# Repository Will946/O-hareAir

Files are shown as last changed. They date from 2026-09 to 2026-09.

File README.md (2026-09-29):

# O'Hare Air

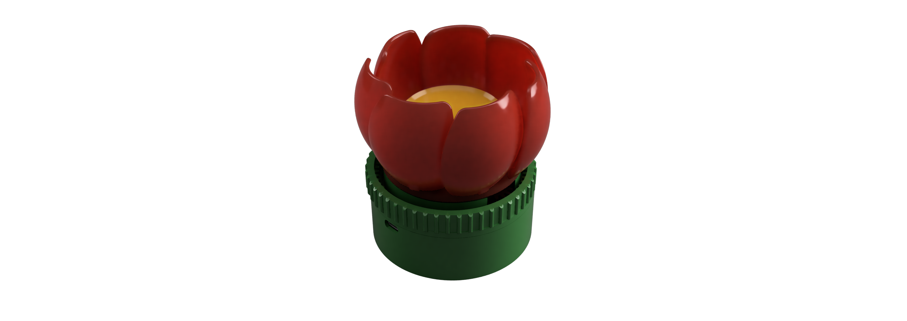
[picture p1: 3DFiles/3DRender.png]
O'Hare Air, assembled and running


A desktop air quality monitor shaped like a flower. It watches temperature, humidity, and air quality (eCO2/eTVOC/AQI-UBA) with a ScioSense ENS161 + ENS210, points a physical stepper-driven needle at the current rating, glows green-to-red through an RGB LED, and serves a full live dashboard over Wi-Fi with history and CSV export. No app, no cloud, no account.

---

## Where the name comes from

The name is taken from The Lorax (2012). In the film, Aloysius O'Hare is the mayor of Thneedville and the founder/CEO of "O'Hare Air," a company that sells bottled air to the town after industrial pollution ruined the natural air supply. This project borrows the name "O'Hare Air" for a device that measures real air quality.

---

## Table of contents

- [Features](#features)
- [How it all fits together](#how-it-all-fits-together)
- [Hardware — two PCB generations](#hardware--two-pcb-generations)
  - [V1 — ESP32-S3 dev-board shield](#v1--esp32-s3-dev-board-shield)
  - [V2 — custom ESP32-H2 module board](#v2--custom-esp32-h2-module-board)
  - [V1 vs V2 at a glance](#v1-vs-v2-at-a-glance)
- [Firmware](#firmware)
  - [Startup and timing](#startup-and-timing)
  - [How air quality is measured and calculated](#how-air-quality-is-measured-and-calculated)
  - [Temperature and humidity](#temperature-and-humidity)
  - [The needle](#the-needle)
  - [The LED](#the-led)
  - [History logging](#history-logging)
- [The web dashboard](#the-web-dashboard)
- [Flashing it yourself](#flashing-it-yourself)
- [Known limitations](#known-limitations)

---

## Features

- **Real air-quality sensing**: ScioSense ENS161 (eTVOC, eCO2, and an onboard 1-5 AQI-UBA rating) plus an ENS210 for temperature and humidity.
- **A physical gauge**: a 28BYJ-48 stepper motor sweeps a needle from 0° to 180° across five ratings: Excellent, Good, Moderate, Poor, Unhealthy.
- **A living LED**: a smooth green-to-red gradient that tracks the current rating, and a slow blue pulse while the sensor is still warming up.
- **A full web dashboard**: live readings, up to seven days of on-device history with min/avg/max, CSV export, and manual needle/LED control, all served directly from the board over Wi-Fi.
- **Two hardware generations**: a shield that plugs onto an off-the-shelf ESP32-S3 dev board (V1), and a from-scratch, coin-sized board built around a bare ESP32-H2 module (V2).
- **A 3D-printed flower enclosure**, because an air monitor sitting on your desk should look like it belongs there.

---

## How it all fits together

```
        ENS210 (temp/RH) ──┐
                            ├──► ESP32 ──► 28BYJ-48 stepper ──► needle (0°-180°)
        ENS161 (AQI-UBA,   ─┘      │
        eTVOC, eCO2)               ├──► RGB LED (green → yellow → orange → red)
                                    │
                                    └──► Wi-Fi ──► built-in web dashboard
                                              (Live / History / Needle tabs)
```

Both sensors sit on the same I2C bus. Every reading cycle, the firmware pulls temperature and humidity from the ENS210, feeds them to the ENS161 as environmental compensation (metal-oxide gas sensors need to know how hot and humid the air is to interpret resistance changes correctly), then reads the ENS161's eTVOC, eCO2, and AQI-UBA registers. AQI-UBA, the sensor's own 1-5 classification, is what drives the needle and the LED. Everything is also pushed out over the board's Wi-Fi web server so it's watchable from a phone or laptop in real time.

---

## Hardware — two PCB generations

### V1 — ESP32-S3 dev-board shield

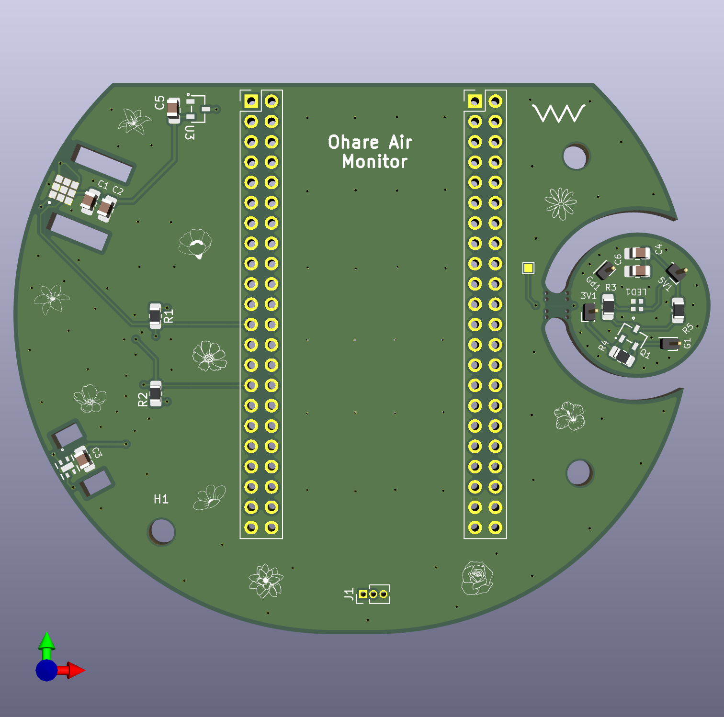
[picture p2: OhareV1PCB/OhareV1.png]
V1 PCB


V1 is a **shield**: a round board with two 2×22 headers (`J9`/`J10`) that plug directly onto an **ESP32-S3-DevKitC-1** dev board, using its pinout exactly. Rather than design a whole MCU circuit, V1 borrows the dev board's regulator, USB-to-serial bridge, and antenna, so the custom PCB only has to carry the sensors, the LED driver, and a 1.8 V rail.

**On the shield itself:**

| Ref | Part | Purpose |
|---|---|---|
| U1 | ENS161-BLGT | Air quality sensor (I2C `0x52`), eTVOC, eCO2, AQI-UBA |
| U2 | ENS210-LQFM | Temperature/humidity sensor (I2C `0x43`) |
| U3 | MCP1700T-1802E | Linear regulator, 3.3 V → 1.8 V for the ENS161's `VDD` rail |
| R1, R2 | 10 kΩ | I2C pull-ups (SCL/SDA) |
| C1–C6 | 0.1 µF / 10 µF | Decoupling for the sensors and the LED |
| Q1 | BSS138 | N-MOSFET level shifter, 3.3 V logic → 5 V for the LED data line |
| LED1 | IN-PI15TAT5R5G5B | A single addressable RGB LED |
| J1 | 3-pin socket | Breaks out 5 V / 3.3 V / LED data for the LED module |
| H1–H3, TP1 | — | Mounting holes and a test point |

The two headers expose every GPIO the dev board offers, but the sketch only actually uses a handful of them: `GPIO8`/`GPIO9` for I2C, `GPIO4`–`GPIO7` for the stepper's four ULN2003 driver inputs, and `GPIO48` for the dev board's own onboard RGB LED. 

Full schematic: [`OhareV1PCB/OhareV1Sch.pdf`](OhareV1PCB/OhareV1Sch.pdf). Manufacturing files (Gerbers) are in [`OhareV1PCB/Gerber.zip`](OhareV1PCB/Gerber.zip); KiCad source is [`OhareV1.kicad_pcb`](OhareV1PCB/OhareV1.kicad_pcb) / [`OhareV1.kicad_sch`](OhareV1PCB/OhareV1.kicad_sch).

### V2 — custom ESP32-H2 module board

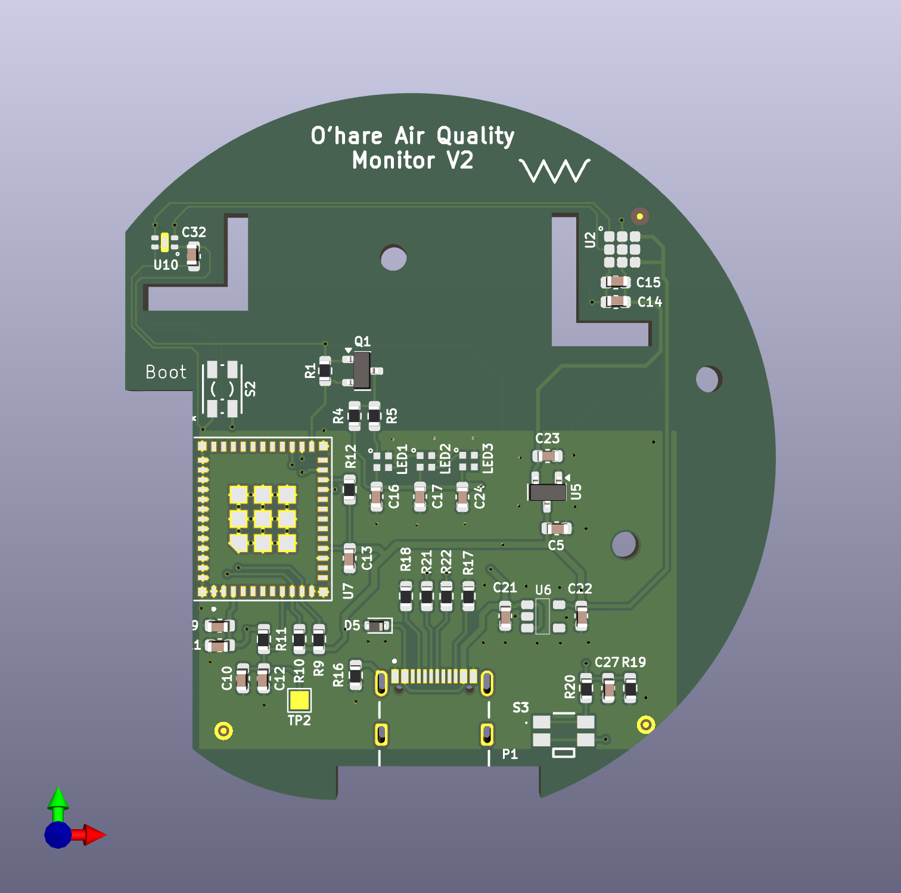
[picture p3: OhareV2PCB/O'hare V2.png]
V2 PCB


V2 throws out the dev board entirely. Instead of two headers plugging into someone else's board, V2 puts an **ESP32-H2-MINI-1** module (a tiny, low-power Espressif module, not a full development board) directly on the PCB, along with its own USB-C connector and its own power regulation. The result is dramatically smaller: the whole "computer" fits in the footprint of the module itself, not a full dev-board-shaped hole in the middle of the design.

**On the V2 board:**

| Ref | Part | Purpose |
|---|---|---|
| U7 | ESP32-H2-MINI-1 | The microcontroller: BLE + 802.15.4 (Zigbee/Thread) radio, **no Wi-Fi** (see below) |
| U2 | ENS161 | Air quality sensor (I2C `0x52`) |
| U10 | ENS210 | Temperature/humidity sensor (I2C `0x43`) |
| U6 | AP2205 | 3.3 V regulator (the board's main "3V3 bus") |
| U5 | AP2120 | 1.8 V regulator, for the ENS161's `VDD` |
| P1 | USB-C receptacle | Power and native USB flashing (the H2 has built-in USB, no separate USB-serial chip needed) |
| D5 | TPD1E10B06 | ESD/surge protection on the USB data lines |
| R21, R22 | 5.1 kΩ | USB-C CC pull-downs, so the board correctly identifies itself as a 5 V sink to chargers and power banks |
| Q1 | BSS138 | Same level-shifting job as V1: 3.3 V logic to 5 V LED data |
| LED1, LED2, LED3 | IN-PI15TAT5R5G5B | **Three** addressable RGB LEDs (labeled Front Left / Front Right / Rear Right on the silkscreen), daisy-chained, instead of V1's single LED |
| S2 | Push button | BOOT (bootloader entry for flashing) |
| S3 | Push button | Reset |

Full schematic: [`OhareV2PCB/OhareV2Sch.pdf`](OhareV2PCB/OhareV2Sch.pdf); KiCad source is [`OhareV2.kicad_pcb`](OhareV2PCB/OhareV2.kicad_pcb) / [`OhareV2.kicad_sch`](OhareV2PCB/OhareV2.kicad_sch).

### V1 vs V2 at a glance

| | V1 | V2 |
|---|---|---|
| MCU | ESP32-S3-DevKitC-1 (full dev board, plugged in via headers) | ESP32-H2-MINI-1 (bare module, soldered directly to the PCB) |
| Radio | Wi-Fi + BLE | BLE + 802.15.4 (Zigbee/Thread); no Wi-Fi |
| Size | Dev-board-sized | A fraction of that; the module is the board |
| Power in | Through the dev board's own USB-C | Native USB-C directly on the PCB |
| LEDs | 1 (drives the dev board's onboard LED) | 3, individually placed under the enclosure's petals |
| Flashing | Dev board's onboard USB-to-serial bridge | Native USB on the H2 itself |
| Firmware status | **Fully supported**, this is what the current sketch targets | **Current firmware is supported on new version |

---

## Firmware

The active firmware is [`Code/OhareAir/OhareAir.ino`](Code/OhareAir/OhareAir.ino), an Arduino sketch built for the **ESP32-S3 (V1)**. It's written directly against the ENS161 and ENS210 datasheets: talking to both sensors over I2C, driving the stepper needle and RGB LED, and serving the whole web dashboard, all from a single self-contained sketch.

### Startup and timing

On power-up, both sensors initialize immediately, but **nothing is read for the first 3 minutes.** The ENS161 needs that long to reach a stable operating temperature; reading it earlier just produces noise. During this warm-up the LED pulses a slow blue instead of showing a color it can't back up yet, and the needle stays parked at 0°.

Once warm-up ends, the firmware takes **one reading per minute**. A flower on a desk doesn't need second-by-second air-quality updates, and a slower cadence keeps the I2C bus quieter.

Each reading cycle:
1. Read temperature and humidity from the ENS210.
2. Write those values to the ENS161's compensation registers (`TEMP_IN` / `RH_IN`), so its gas readings account for the current conditions.
3. Give the ENS161 a moment to fold that compensation into its next internal measurement.
4. Read eTVOC, eCO2, and AQI-UBA off the ENS161.
5. Feed everything into the 5-minute history accumulator.
6. If Auto mode is on, hand AQI-UBA to the needle logic.

### How air quality is measured and calculated

The ENS161 is a metal-oxide gas sensor: it doesn't count individual VOC molecules, it measures how much a heated sensing element's electrical resistance shifts when exposed to reactive gases, then converts that into three numbers over I2C:

- **eTVOC** (equivalent Total Volatile Organic Compounds, in ppb): the chip's estimate of total VOC concentration, calibrated against ethanol as a reference gas. This is the sensor's actual measurement; everything else is derived from it.
- **eCO2** (equivalent CO2, in ppm): not a real CO2 measurement. It's estimated from the same VOC signal, so it tracks eTVOC almost exactly and should be read as "how stale does the air smell," not literal CO2 concentration.
- **AQI-UBA** (1-5): the chip's own onboard hygienic rating, computed internally by ScioSense's proprietary algorithm from its eTVOC signal, using threshold bands published by Germany's Federal Environmental Agency (Umweltbundesamt, hence "UBA"):

  | AQI-UBA | Rating | Approx. eTVOC |
  |---|---|---|
  | 1 | Excellent | 0 – 65 ppb |
  | 2 | Good | 65 – 220 ppb |
  | 3 | Moderate | 220 – 650 ppb |
  | 4 | Poor | 650 – 2,200 ppb |
  | 5 | Unhealthy | 2,200 ppb+ |

**AQI-UBA is what drives the needle and the LED**, rather than a hand-built formula. eTVOC and eCO2 are still read, displayed, and logged, but the rating itself comes straight from the ENS161's own proprietary onboard algorithm: ScioSense's classification, computed inside the chip from its own internal, self-compensating signal, not something calculated in software afterward. The trade-off is that AQI-UBA can't be corrected or offset after the fact the way a software-calculated number could; whatever the chip decides, the firmware trusts.

### Temperature and humidity

Raw ENS210 output is corrected by a fixed offset (`TEMP_OFFSET_C`, currently 5.56 °C) to account for the board's own self-heating from the MCU and Wi-Fi radio; an uncorrected reading on this hardware runs noticeably warmer than the actual room. This is a per-board constant; if you build your own, re-measure it against a reference thermometer and adjust.

### The needle

A 28BYJ-48 stepper motor (through a ULN2003 driver board) sweeps a needle across a 180° arc:

| Rating | Angle |
|---|---|
| Excellent | 0° |
| Good | 90° |
| Moderate | 115° |
| Poor | 140° |
| Unhealthy | 180° |

To avoid the needle twitching back and forth when AQI-UBA hovers right at a boundary, a new rating has to show up in **two readings in a row** (about two minutes) before the needle actually moves. Position is tracked in software as a step count from a zeroed home position. There's no physical limit switch, so the needle has to be manually set to 0° before every power-up; if the board resets while the needle is elsewhere, the software's idea of "0°" and the needle's real position will disagree until it's re-zeroed by hand.

### The LED

The LED (a single onboard RGB LED on V1; three chained LEDs, wired for that, on V2's hardware) fades smoothly between colors rather than snapping: green at AQI-UBA 1, sliding through yellow and orange, to red at AQI-UBA 5. During warm-up, before any reading exists, it pulses a slow blue instead. Brightness (0/10/30/60/100%) is adjustable from the dashboard and resets to 60% on every reboot; it isn't saved to flash.

### History logging

Every 5 minutes, the firmware saves one entry (the minimum, average, and maximum of temperature, humidity, AQI-UBA, eCO2, and eTVOC over that window) into a ring buffer sized for **7 days** (2,016 entries), packed into a fixed 32-byte record per entry. **This history lives entirely in RAM, not flash**; it's lost on every reboot or power cycle. A window where a sensor read failed is stored as an explicit "no data" marker rather than a guessed value, so a bad reading never silently drags down an average.

---

## The web dashboard

The board runs its own web server (`WebServer.h`) and serves a self-contained single-page dashboard: no external app, no cloud round-trip. Connect it to Wi-Fi, open its IP address in a browser, and you get three tabs:

**Live**

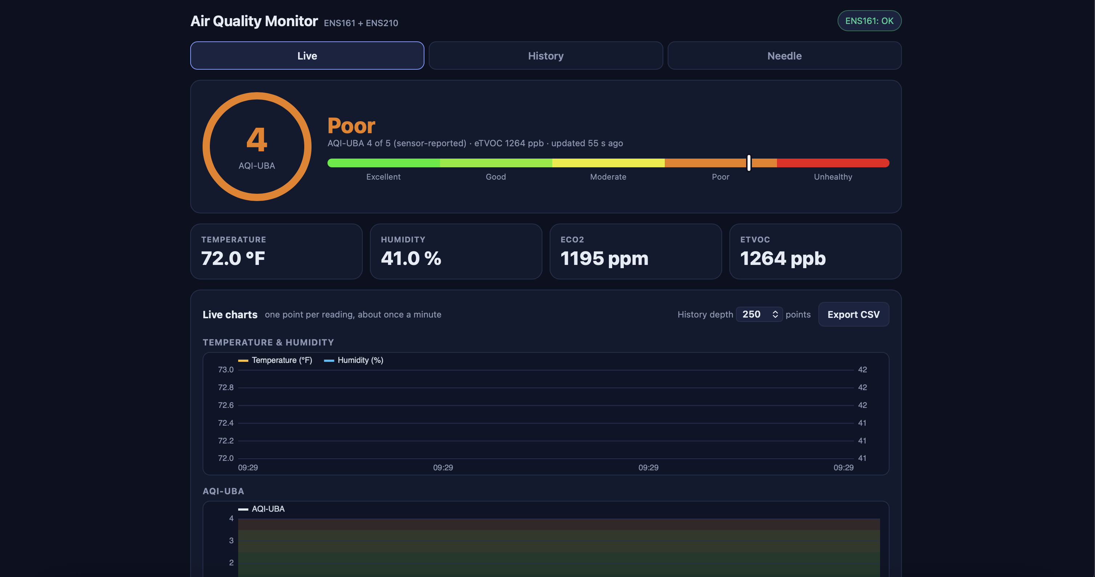
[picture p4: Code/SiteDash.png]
Live tab


The current AQI-UBA rating as a big color-coded number and name, a five-segment scale showing where it sits, temperature/humidity/eCO2/eTVOC cards, and three live-updating charts (temperature & humidity, AQI-UBA, and gas levels) that add one point per new reading, not per page refresh, so leaving the tab open doesn't flood the chart with duplicate points. LED brightness controls live here too.

**History**

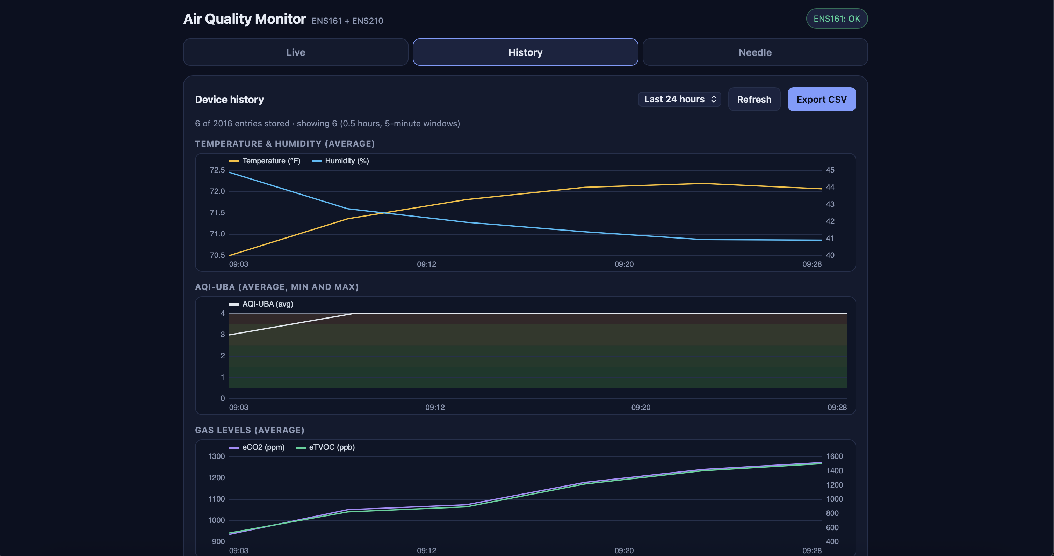
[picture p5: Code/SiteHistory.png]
History tab


The same charts, but built from the on-device 5-minute history instead of the live buffer, with a range selector (6 hours to 7 days) and CSV export.

**Needle**

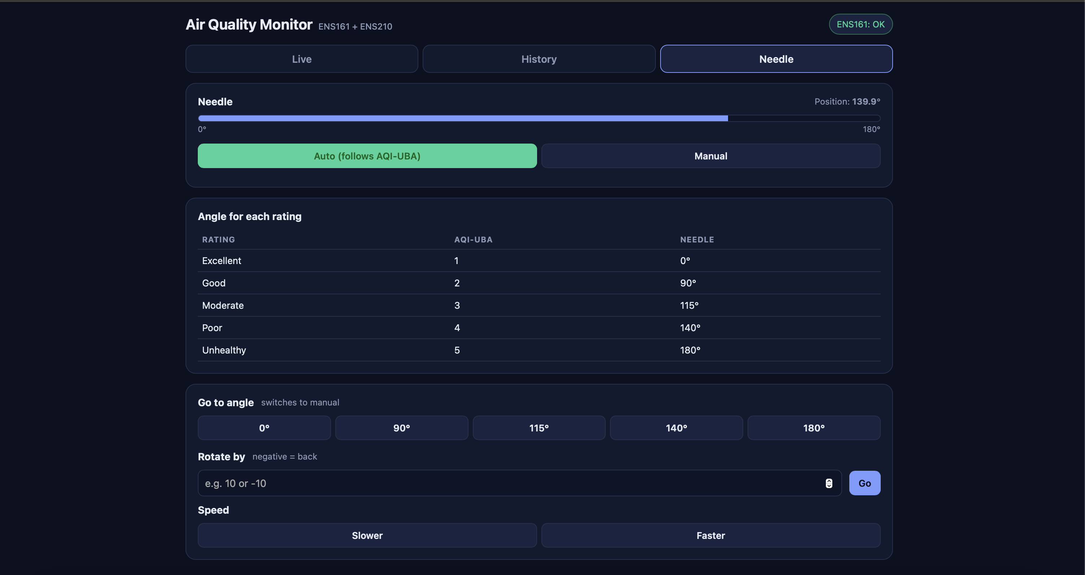
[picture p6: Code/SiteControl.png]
Needle tab


Manual control: an Auto/Manual toggle, a reference table of which AQI-UBA rating maps to which angle, one-tap "go to angle" buttons for each rating, a free-form rotate-by-degrees input, and motor speed adjustment.

**Endpoints**, for anyone scripting against it directly:

| Endpoint | Purpose |
|---|---|
| `GET /status` | Current reading, needle state, and device status as JSON |
| `GET /history?n=N` | The newest N history entries as compact JSON |
| `GET /rotate?degrees=X` | Rotate the needle by X° (switches to Manual) |
| `GET /goto?degrees=X` | Move the needle to an absolute angle (switches to Manual) |
| `GET /mode?auto=0\|1` | Switch between Auto and Manual |
| `GET /speed?direction=faster\|slower` | Adjust stepper speed |
| `GET /brightness?pct=X` | Set LED brightness, 0–100 |

---

## Flashing it yourself

1. Arduino IDE with the ESP32 board package installed, targeting an ESP32-S3 board (V1 hardware).
2. Install the **Adafruit NeoPixel** library. `Wire`, `WiFi`, and `WebServer` ship with the ESP32 core.
3. Open [`Code/OhareAir/OhareAir.ino`](Code/OhareAir/OhareAir.ino) and fill in your Wi-Fi credentials:
```cpp
   const char* ssid = "";
   const char* password = "";
```
4. Flash it, then open the Serial Monitor at 115200 baud; it prints the board's IP address once connected.
5. Set the needle to its physical 0° position before powering on, since the firmware has no way to detect where it actually is.
6. Open that IP address in a browser on the same network.

---

## Known limitations

- **Highly temperature- and humidity-dependent.** The ENS161 is a metal-oxide gas sensor: its readings shift with the temperature and humidity it's told to compensate for, and the board's own self-heating (from the MCU and Wi-Fi radio) pushes the ENS210's raw temperature well above the actual room temperature. That's corrected with a fixed offset (`TEMP_OFFSET_C`) tuned for this specific board; a different enclosure, a different MCU, or even just a different ambient environment can shift the true offset enough that eTVOC, eCO2, and AQI-UBA all read differently than they would with perfect compensation.
- **History doesn't survive a reboot.** It's RAM-only; a power cycle clears it.
- **The needle has no home sensor.** It has to be manually zeroed before every power-up.
- **Wi-Fi credentials are hardcoded** in the sketch, not configurable from the dashboard.
- **No OTA updates**: reflashing means plugging in over USB, which means having to disassemble the enclosure to access the port.

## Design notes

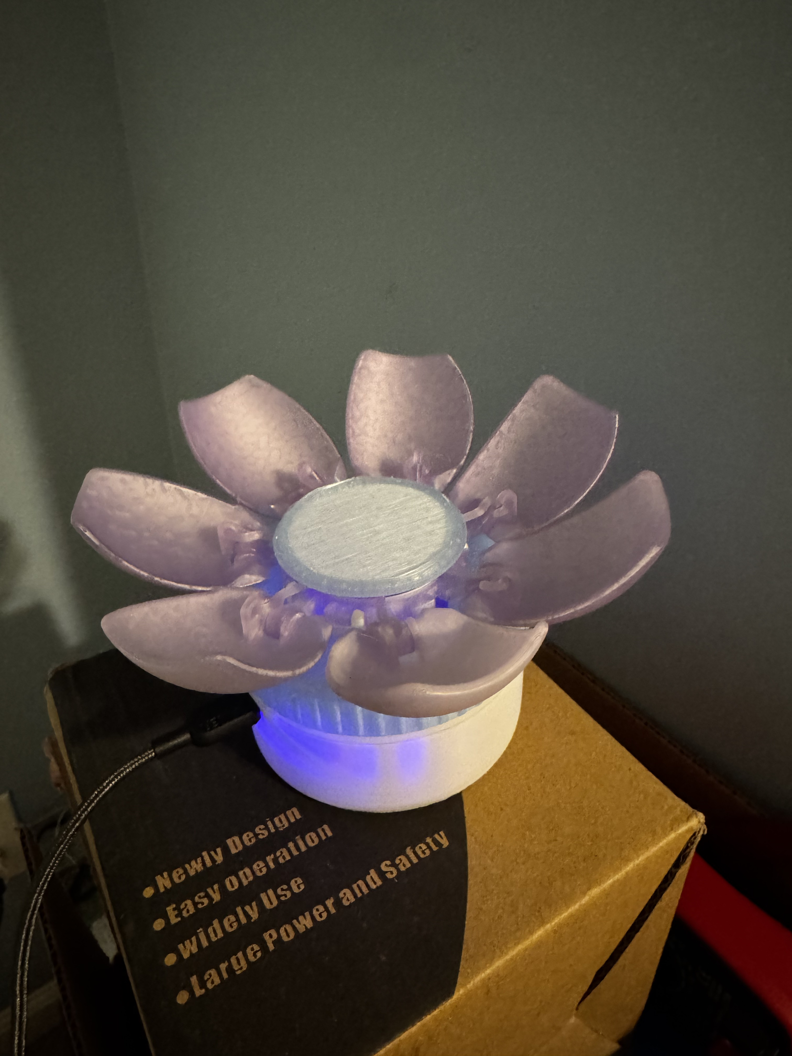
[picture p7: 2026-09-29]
3DFiles/OhareAir.jpeg

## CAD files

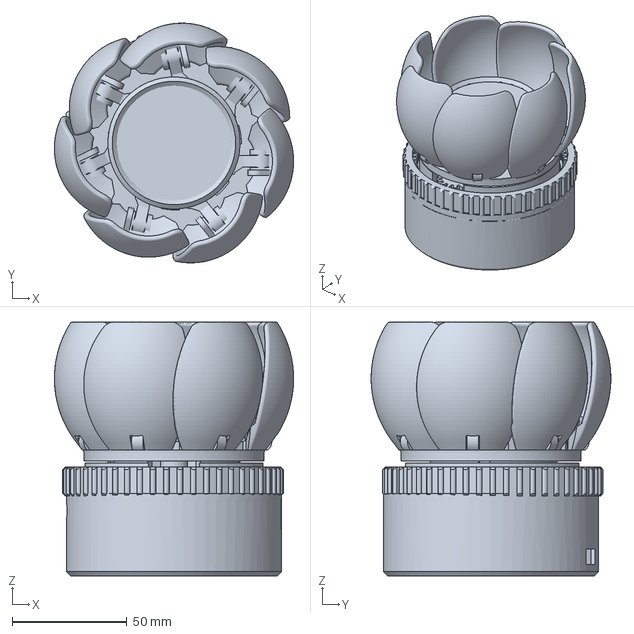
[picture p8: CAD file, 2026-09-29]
3DFiles/OhareAir.3mf
104.2 x 104.4 x 110.6 mm

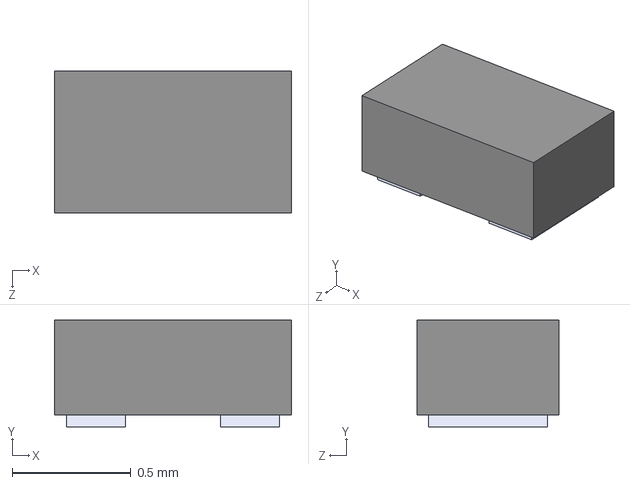
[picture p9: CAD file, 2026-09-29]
OhareV1PCB/Footprint/TPD1E10B06DPYR/TPD1E10B06DPYR.step
1.00 x 0.45 x 0.6 mm

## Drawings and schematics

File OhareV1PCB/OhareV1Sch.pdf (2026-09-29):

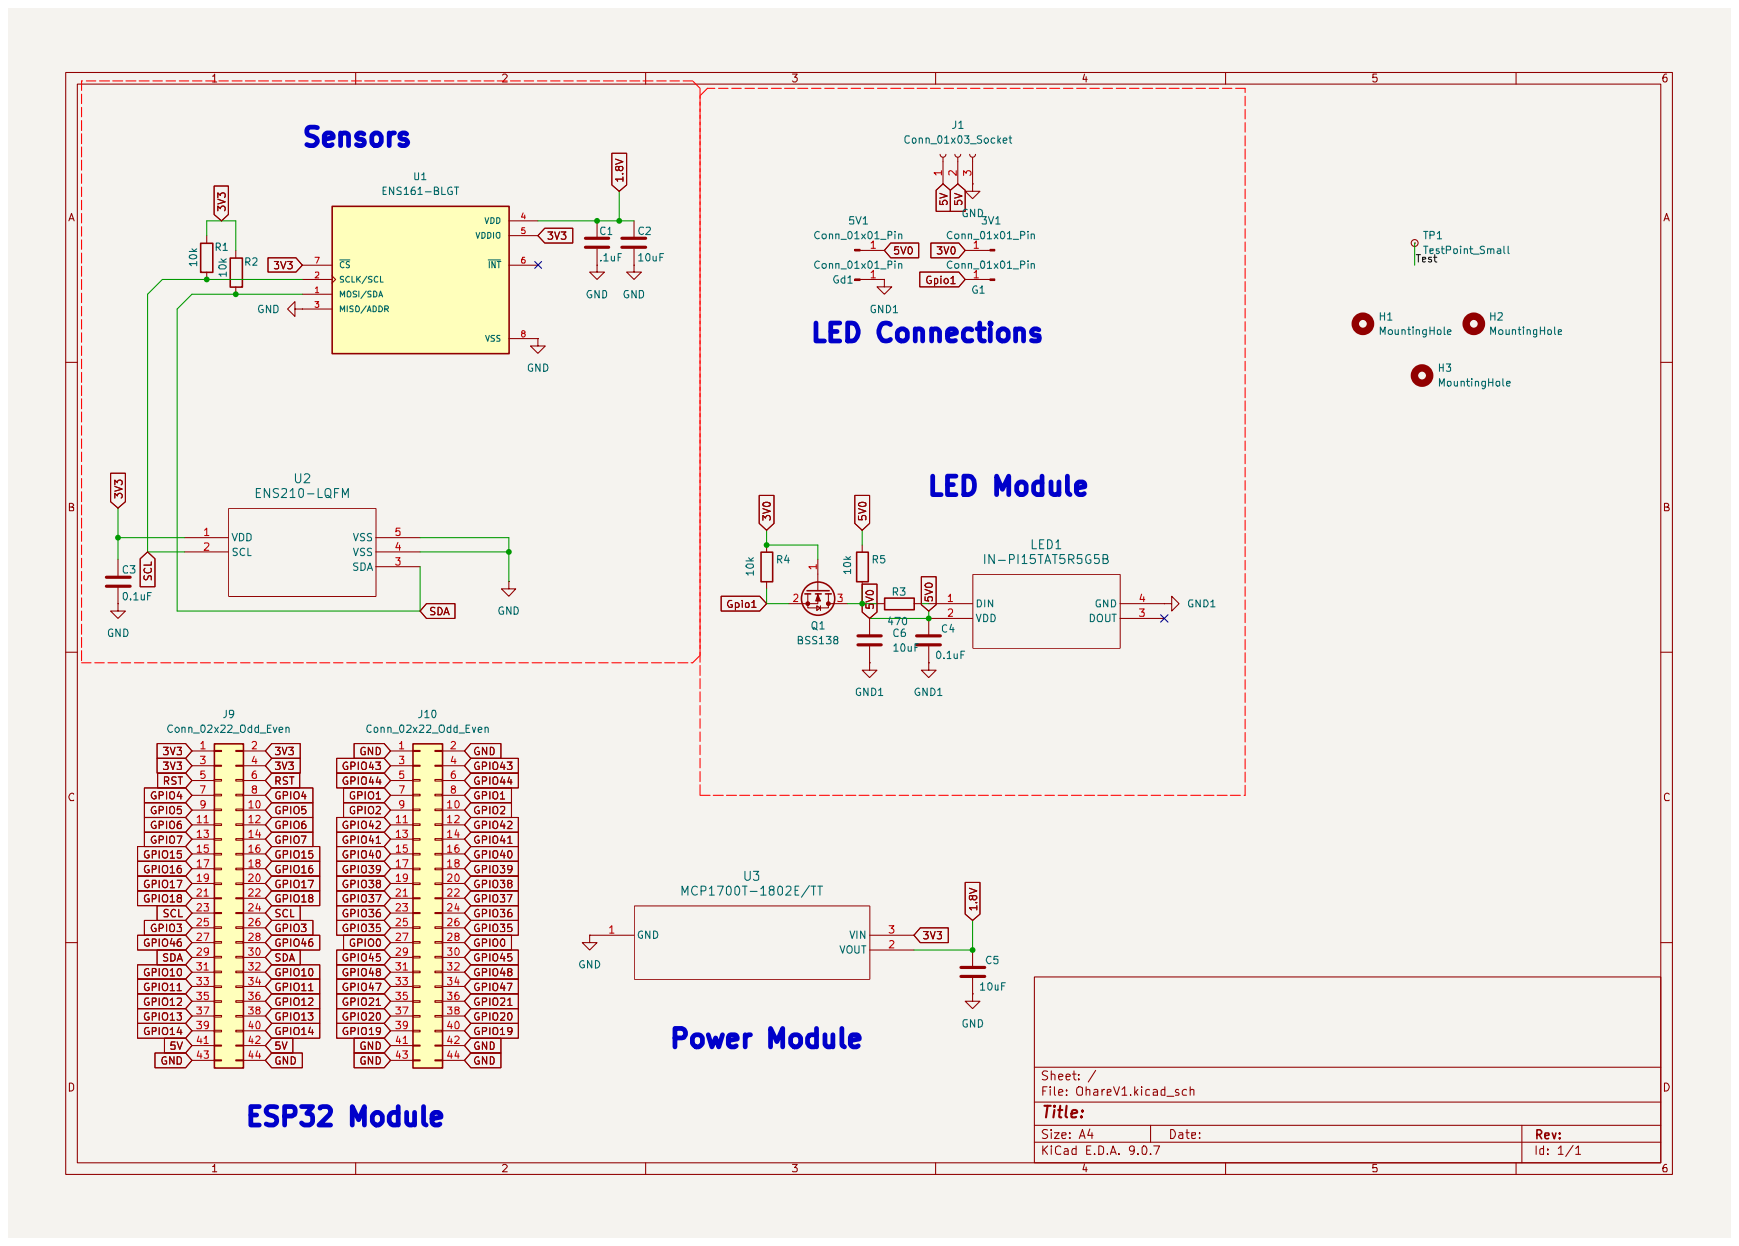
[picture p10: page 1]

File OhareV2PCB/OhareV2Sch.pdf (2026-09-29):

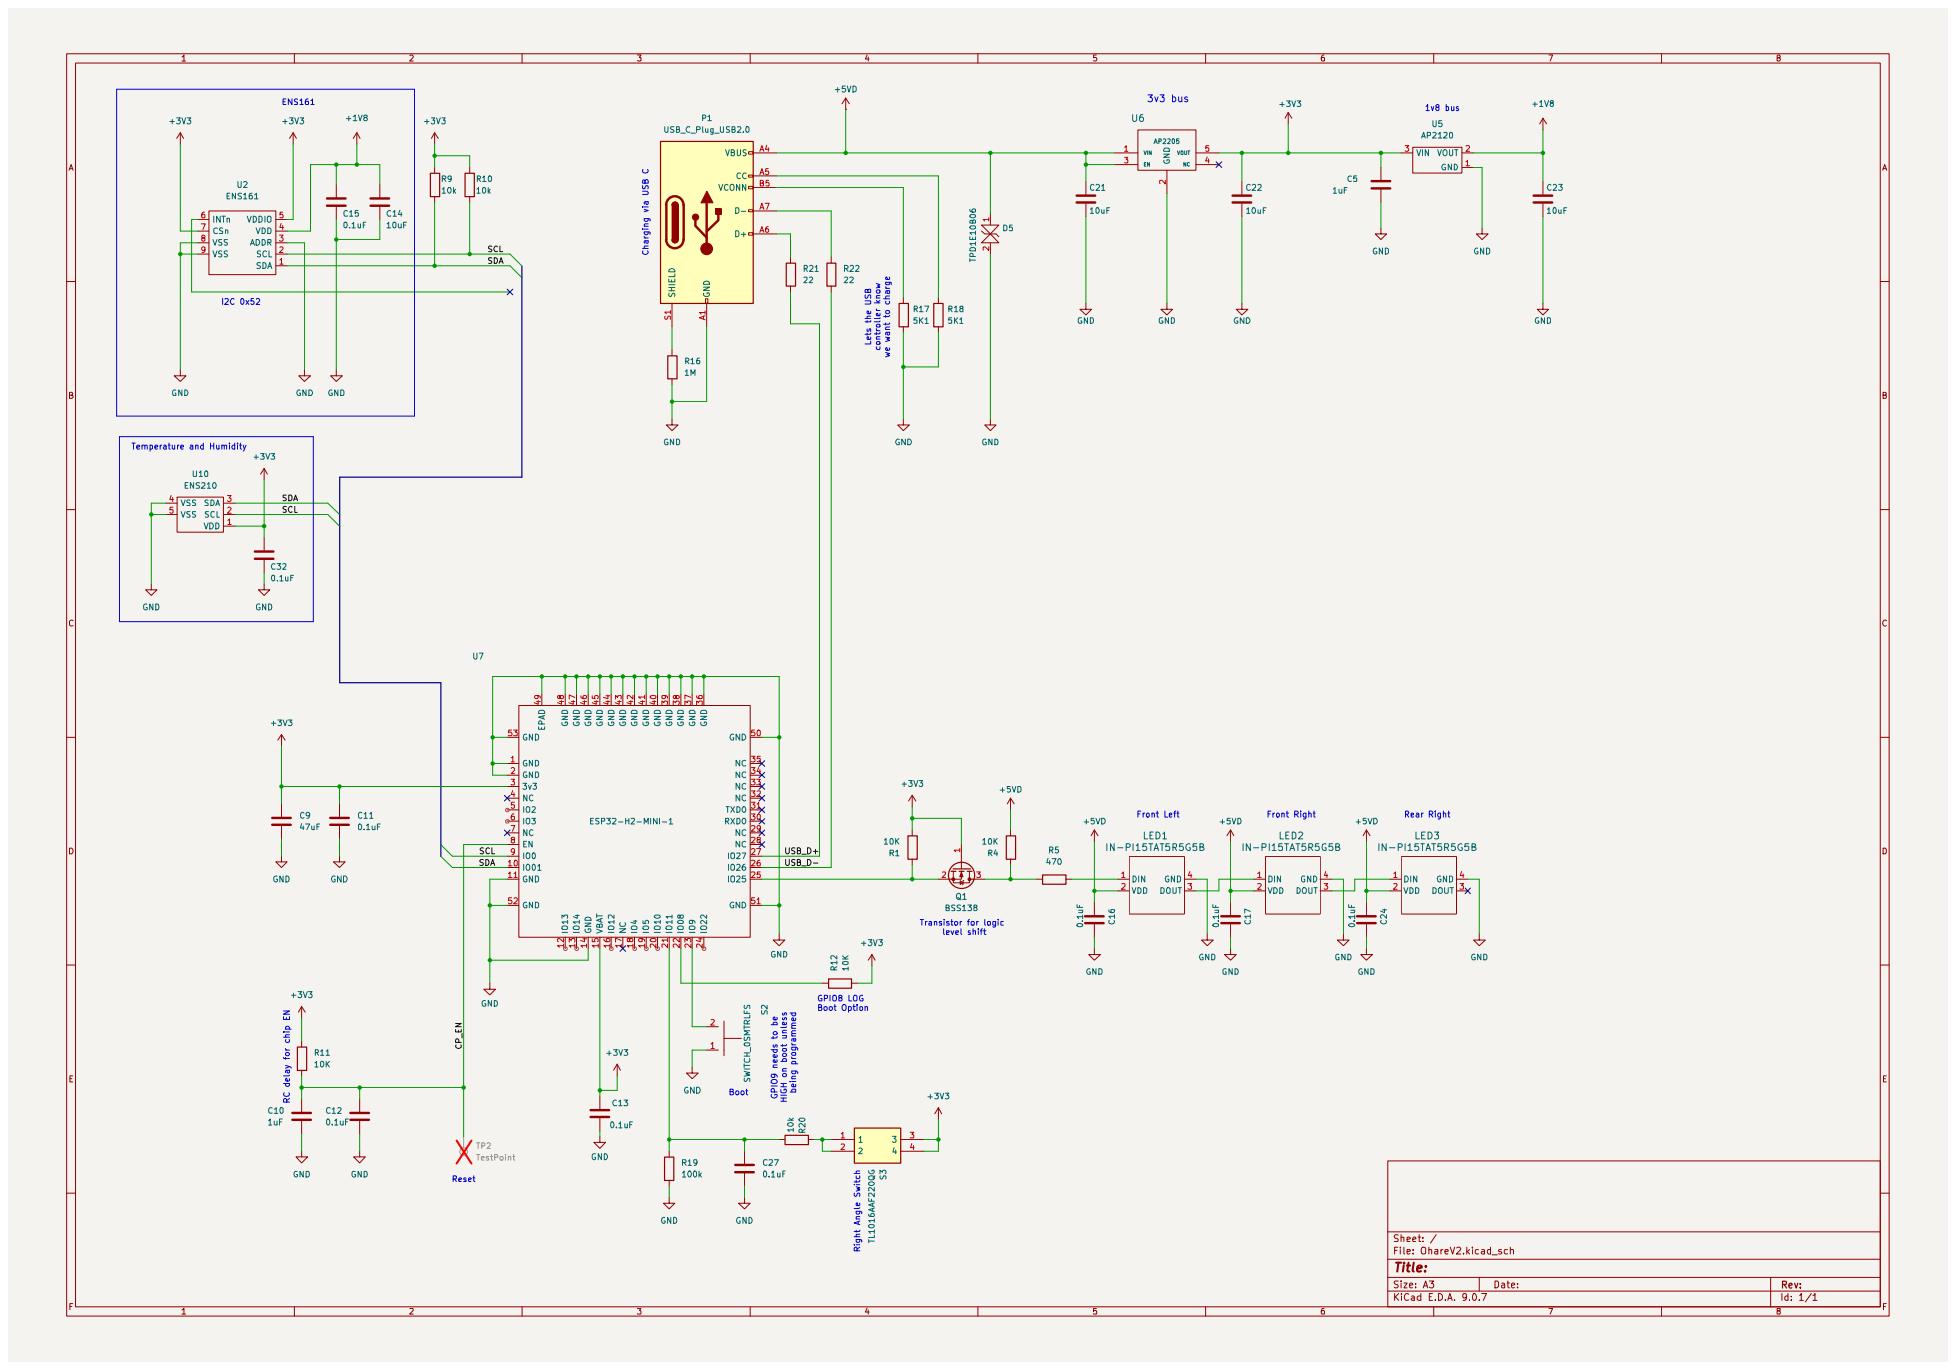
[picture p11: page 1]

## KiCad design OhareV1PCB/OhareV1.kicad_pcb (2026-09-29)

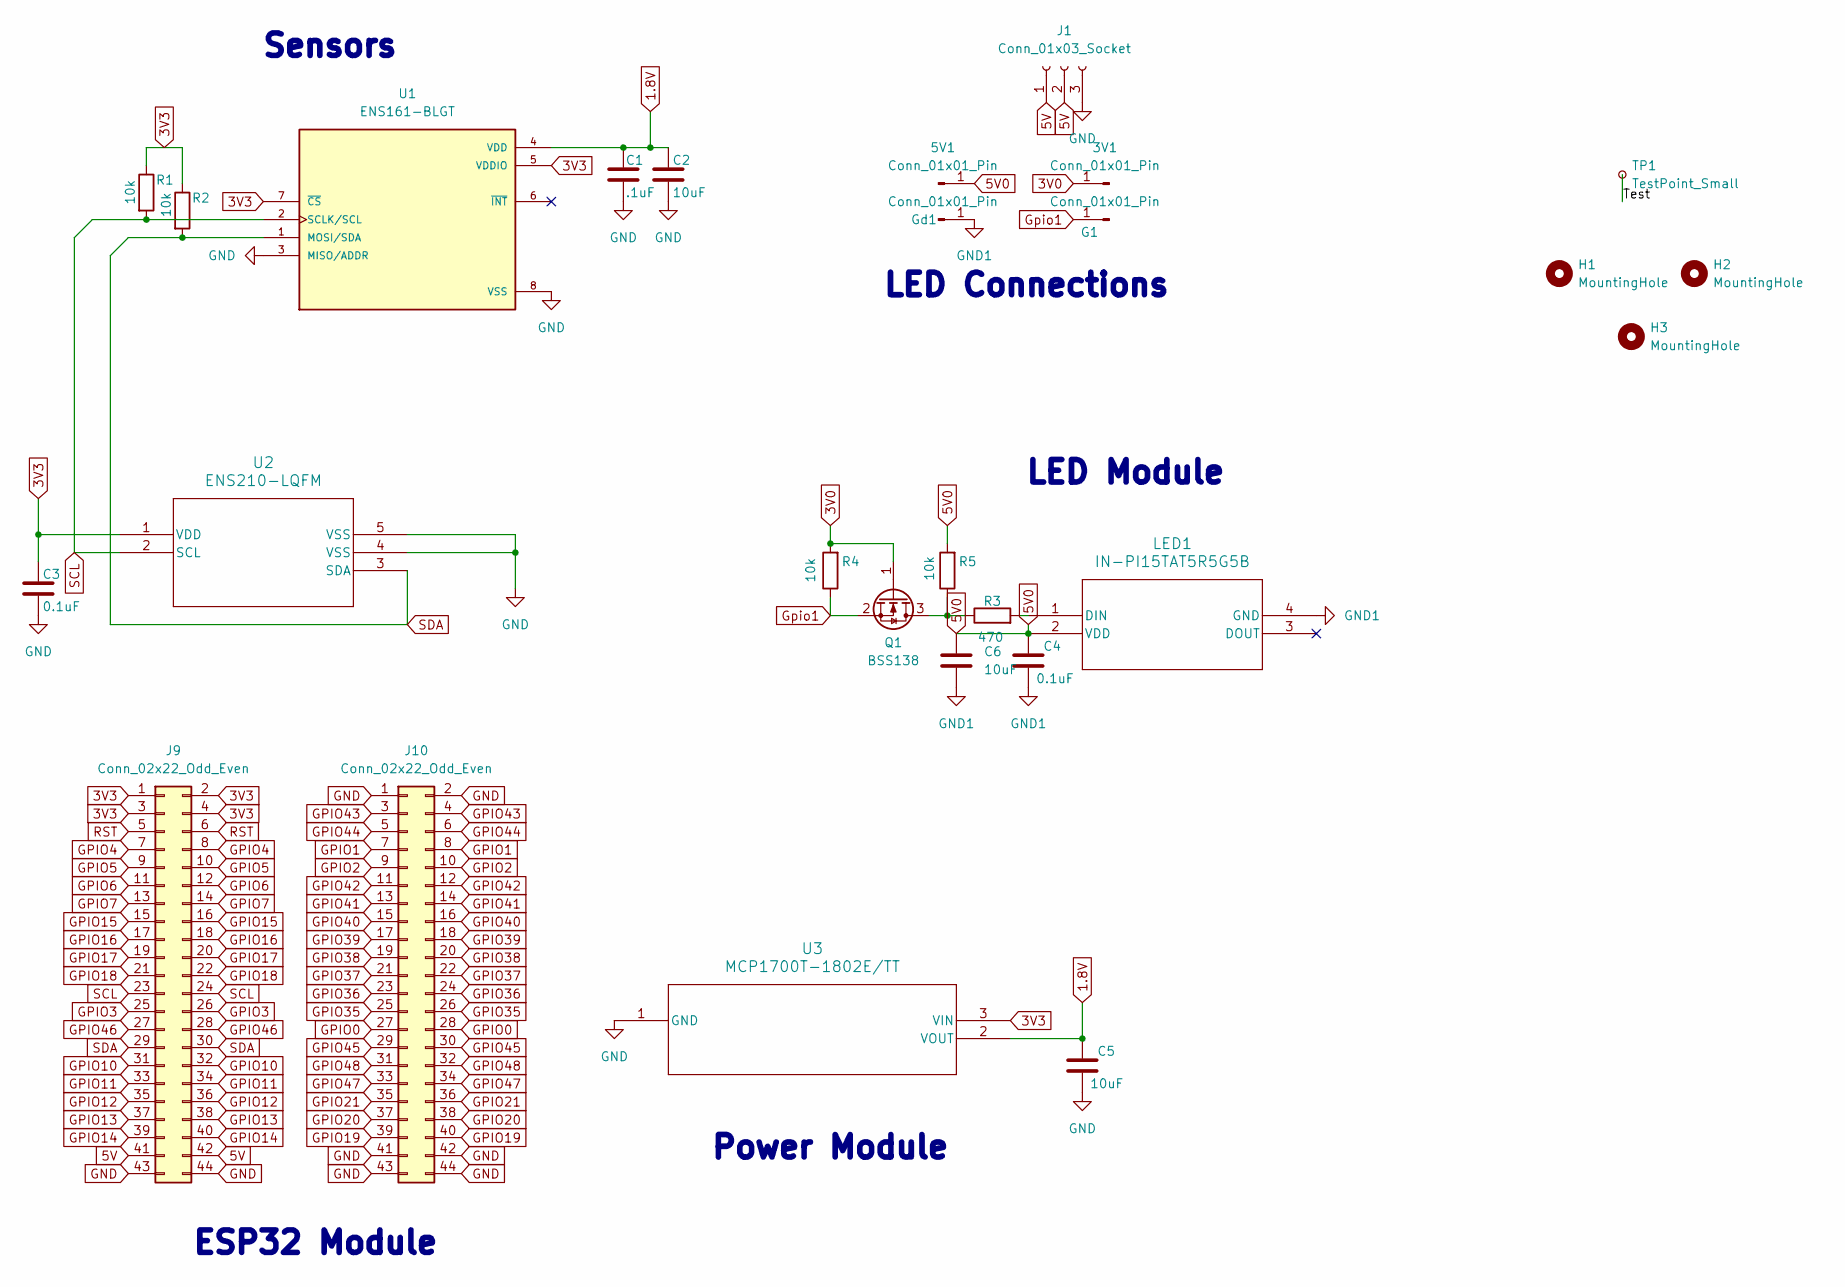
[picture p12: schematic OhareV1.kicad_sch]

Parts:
3V1, 5V1: Conn_01x01_Pin; PinHeader_1x01_P1.27mm_Vertical
C1: .1uF; C_0805_2012Metric_Pad1.18x1.45mm_HandSolder
C2, C5, C6: 10uF; C_0805_2012Metric_Pad1.18x1.45mm_HandSolder
C3, C4: 0.1uF; C_0805_2012Metric_Pad1.18x1.45mm_HandSolder
G1: Conn_01x01_Pin; PinHeader_1x01_P1.27mm_Vertical
Gd1: Conn_01x01_Pin; PinHeader_1x01_P1.27mm_Vertical
H1, H2, H3: MountingHole; MountingHole_3.2mm_M3
J1: Conn_01x03_Socket; PinHeader_1x03_P1.27mm_Vertical
J9, J10: Conn_02x22_Odd_Even; PinHeader_2x22_P2.54mm_Vertical
LED1: IN-PI15TAT5R5G5B; IN-PI15_INL
Q1: BSS138; SOT-23_3L_ONS-L
R1, R2, R4, R5: 10k; R_0805_2012Metric_Pad1.20x1.40mm_HandSolder
R3: 470; R_0805_2012Metric_Pad1.20x1.40mm_HandSolder
TP1: TestPoint_Small; TestPoint_Pad_1.0x1.0mm
U1: ENS161-BLGT; XDCR_ENS161-BLGT; PARTREV 1.3; DigiKey_Part_Number 2618-ENS161-BLGTCT-ND
U2: ENS210-LQFM; SON-04-ENS210_2X2_AMS-L
U3: MCP1700T-1802E/TT; SOT-23_MC_MCH-L

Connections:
1.8V: C1.1, C2.1, C5.1, U1.4 (VDD), U3.2 (VOUT)
3V0: 3V1.1, Q1.1 (G), R4.2
3V3: C3.1, J9.1, J9.2, J9.3, J9.4, R1.1, R2.1, U1.5 (VDDIO), U1.7 (~CS), U2.1 (VDD), U3.3 (VIN)
5V: J1.1, J1.2, J9.41, J9.42
5V0: 5V1.1, C4.1, C6.1, LED1.2 (VDD), R5.2
/Test: TP1.1
GND: C1.2, C2.2, C3.2, C5.2, J1.3, J9.43, J9.44, J10.1, J10.2, J10.41, J10.42, J10.43, J10.44, U1.3 (MISO/ADDR), U1.8 (VSS), U1.9 (VSS), U2.4 (VSS), U2.5 (VSS), U3.1 (GND)
GND1: C4.2, C6.2, Gd1.1, LED1.4 (GND)
GPIO0: J10.27, J10.28
GPIO1: J10.7, J10.8
GPIO2: J10.9, J10.10
GPIO3: J9.25, J9.26
GPIO4: J9.7, J9.8
GPIO5: J9.9, J9.10
GPIO6: J9.11, J9.12
GPIO7: J9.13, J9.14
GPIO10: J9.31, J9.32
GPIO11: J9.33, J9.34
GPIO12: J9.35, J9.36
GPIO13: J9.37, J9.38
GPIO14: J9.39, J9.40
GPIO15: J9.15, J9.16
GPIO16: J9.17, J9.18
GPIO17: J9.19, J9.20
GPIO18: J9.21, J9.22
GPIO19: J10.39, J10.40
GPIO20: J10.37, J10.38
GPIO21: J10.35, J10.36
GPIO35: J10.25, J10.26
GPIO36: J10.23, J10.24
GPIO37: J10.21, J10.22
GPIO38: J10.19, J10.20
GPIO39: J10.17, J10.18
GPIO40: J10.15, J10.16
GPIO41: J10.13, J10.14
GPIO42: J10.11, J10.12
GPIO43: J10.3, J10.4
GPIO44: J10.5, J10.6
GPIO45: J10.29, J10.30
GPIO46: J9.27, J9.28
GPIO47: J10.33, J10.34
GPIO48: J10.31, J10.32
Gpio1: G1.1, Q1.2 (S), R4.1
unnamed: LED1.1 (DIN), R3.2
unnamed: Q1.3 (D), R3.1, R5.1
RST: J9.5, J9.6

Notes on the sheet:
LED Connections
ESP32 Module
LED Module
Power Module
Sensors

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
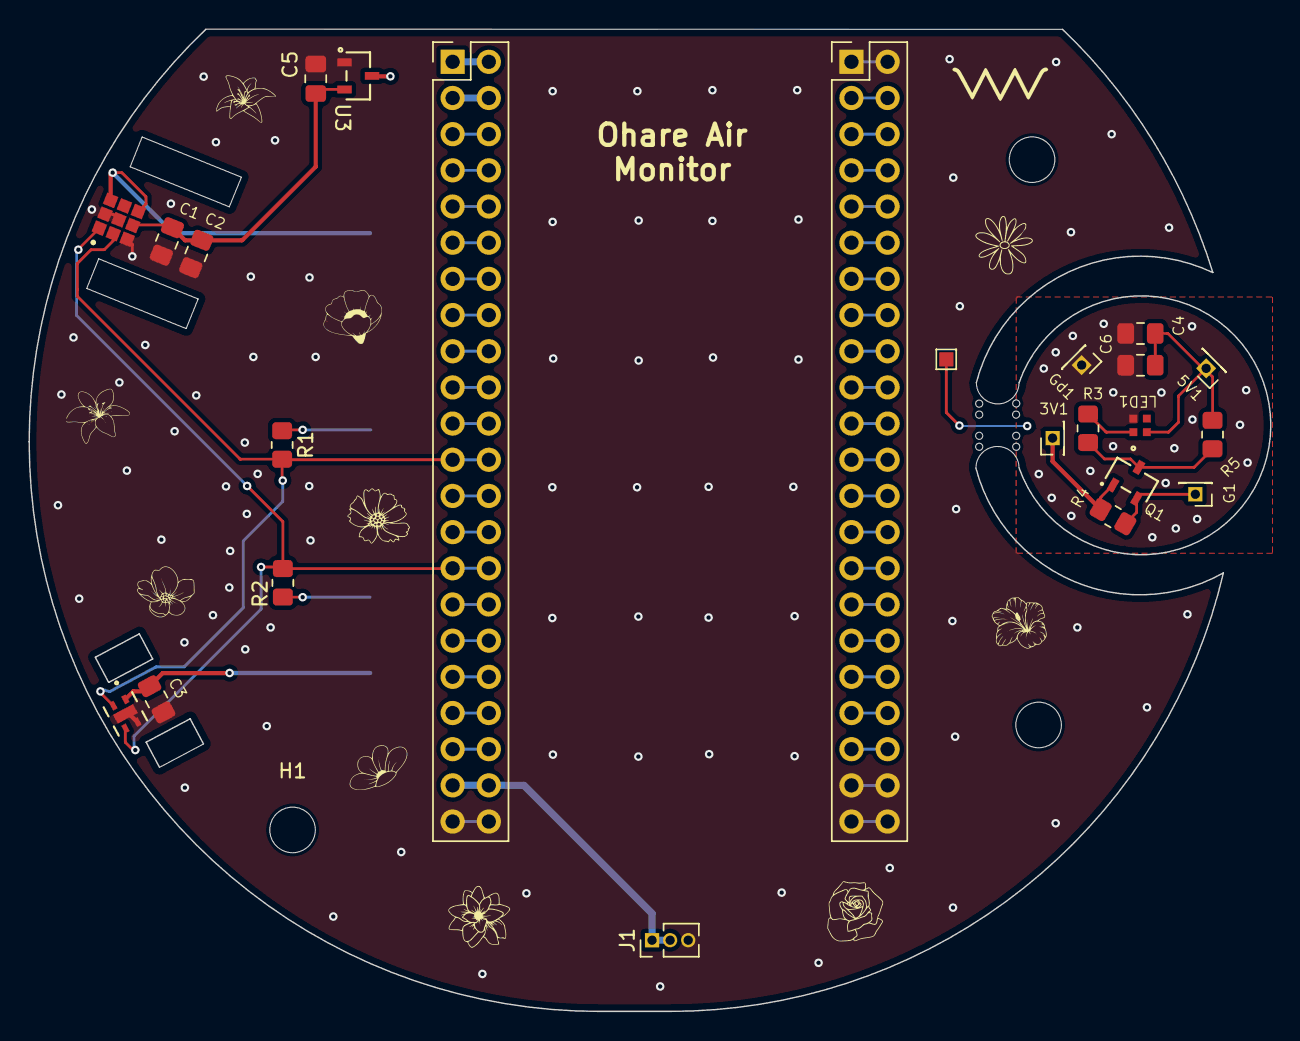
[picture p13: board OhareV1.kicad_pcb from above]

Board: 2 copper layers, 87.2 x 69.0 mm, 28 parts (0 on the bottom side), 47 nets.

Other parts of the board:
mouse-bite-3mm-6mm: VAL**; mouse-bite-3mm-6mm

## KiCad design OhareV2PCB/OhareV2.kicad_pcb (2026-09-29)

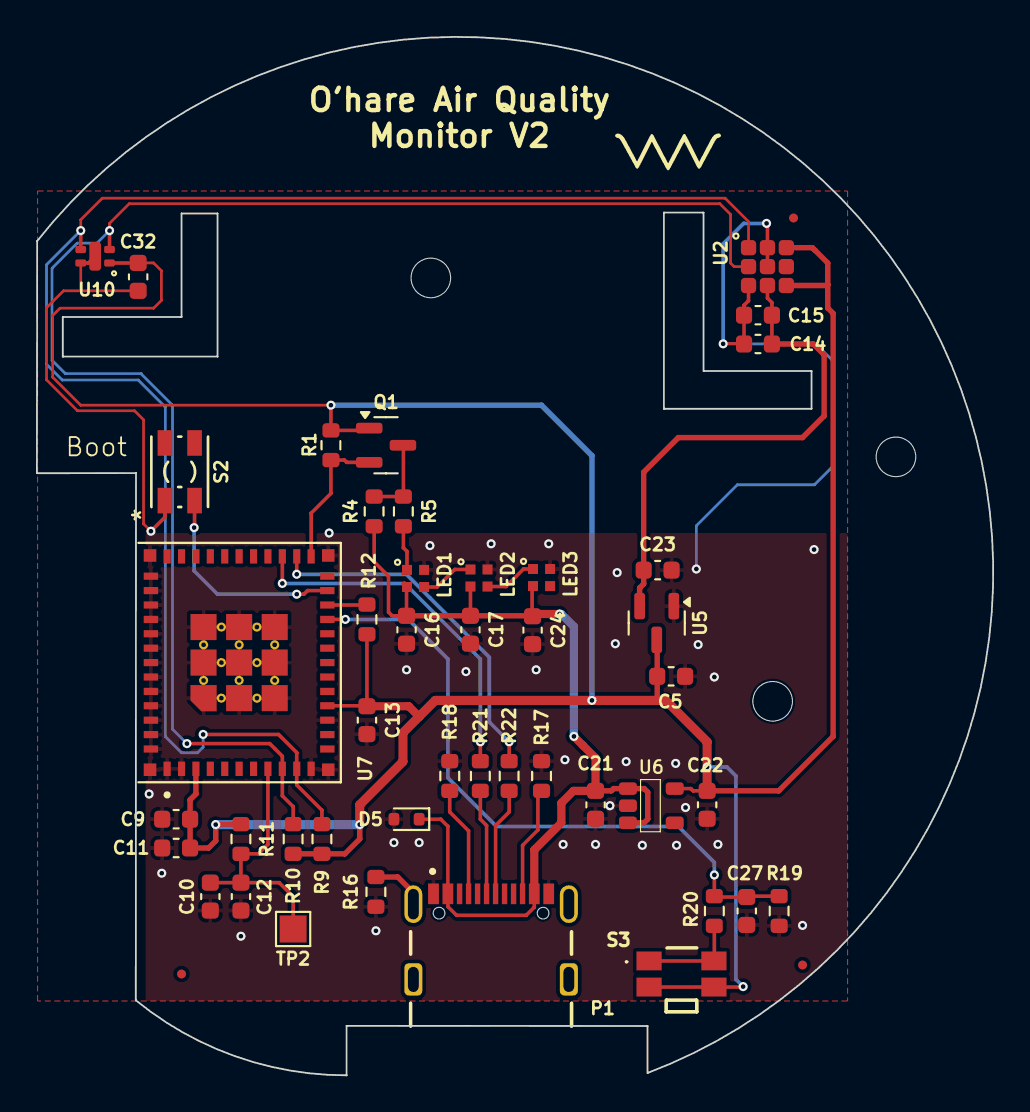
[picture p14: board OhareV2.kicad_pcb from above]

Board: 2 copper layers, 53.1 x 57.7 mm, 44 parts (0 on the bottom side), 23 nets.

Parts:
C5, C10: 1uF; C_0603_1608Metric
C9: 47uF; C_0603_1608Metric
C11, C12, C13, C15, C16, C17, C24, C27, C32: 0.1uF; C_0603_1608Metric
C14, C21, C22, C23: 10uF; C_0603_1608Metric
D5: TPD1E10B06; D_SOD-523
LED1, LED2, LED3: IN-PI15TAT5R5G5B; IN-PI15_INL
P1: USB_C_Plug_USB2.0; GCT_USB4105-GF-A
Q1: BSS138; SOT-23
R1, R4, R11, R12: 10K; R_0603_1608Metric
R5: 470; R_0603_1608Metric
R9, R10, R20: 10k; R_0603_1608Metric
R16: 1M; R_0603_1608Metric
R17, R18: 5K1; R_0603_1608Metric
R19: 100k; R_0603_1608Metric
R21, R22: 22; R_0603_1608Metric
S2: SWITCH_0SMTRLFS
S3: TL1016AAF220QG
TP2: TestPoint; TestPoint_Pad_1.5x1.5mm
U2: ENS161
U5: AP2120; SOT-23
U6: AP2205; AP2204
U7: ESP32-H2-MINI-1; MODULE_ESP32-H2-MINI-1-H2
U10: ENS210

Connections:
+1V8: C14.1, C15.1, C23.1, U2.4 (VDD), U5.2 (VOUT)
+3V3: C5.1, C9.1, C11.1, C13.1, C22.1, C32.1, Q1.1 (G), R1.2, R9.1, R10.1, R11.1, R12.2, S3.3, S3.4, U2.5 (VDDIO), U2.7 (CSn), U5.3 (VIN), U6.5 (VOUT), U7.3 (3v3), U7.15 (VBAT), U10.1 (VDD)
+5VD: C16.1, C17.1, C21.1, C24.1, D5.1, LED1.2 (VDD), LED2.2 (VDD), LED3.2 (VDD), P1.A4 (VBUS), P1.A9 (VBUS), R4.2, U6.1 (VIN), U6.3 (EN)
/CP_EN: C10.1, C12.1, R11.2, TP2.1, U7.8 (EN)
/SCL: R10.2, U2.2 (SCL), U7.9 (IO0), U10.2 (SCL)
/SDA: R9.2, U2.1 (SDA), U7.10 (IO01), U10.3 (SDA)
/USB_D+: R21.1, U7.27 (IO27)
/USB_D-: R22.2, U7.26 (IO26)
GND: C5.2, C9.2, C10.2, C11.2, C12.2, C13.2, C14.2, C15.2, C16.2, C17.2, C21.2, C22.2, C23.2, C24.2, C27.2, C32.2, D5.2, LED1.4 (GND), LED2.4 (GND), LED3.4 (GND), P1.A1 (GND), P1.A12 (GND), R16.2, R17.2, R18.2, R19.2, S2.1, U2.3 (ADDR), U2.8 (VSS), U2.9 (VSS), U5.1 (GND), U6.2 (GND), U7.1 (GND), U7.2 (GND), U7.11 (GND), U7.14 (GND), U7.36 (GND), U7.37 (GND), U7.38 (GND), U7.39 (GND), U7.40 (GND), U7.41 (GND), U7.42 (GND), U7.43 (GND), U7.44 (GND), U7.45 (GND), U7.46 (GND), U7.47 (GND), U7.48 (GND), U7.49 (EPAD), U7.50 (GND), U7.51 (GND), U7.52 (GND), U7.53 (GND), U10.4 (VSS), U10.5 (VSS)
unnamed: LED1.1 (DIN), R5.2
unnamed: LED1.3 (DOUT), LED2.1 (DIN)
unnamed: LED2.3 (DOUT), LED3.1 (DIN)
unnamed: P1.A5 (CC), R18.1
unnamed: P1.A6 (D+), R21.2
unnamed: P1.A7 (D-), R22.1
unnamed: P1.S1 (SHIELD), R16.1
unnamed: P1.B5 (VCONN), R17.1
unnamed: Q1.3 (D), R4.1, R5.1
unnamed: Q1.2 (S), R1.1, U7.25 (IO25)
unnamed: R20.2, S3.1, S3.2
unnamed: R12.1, U7.22 (IO08)
unnamed: S2.2, U7.23 (IO9)
unnamed: C27.1, R19.1, R20.1, U7.21 (IO11)

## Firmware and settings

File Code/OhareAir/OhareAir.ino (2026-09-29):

// ===== AIRCUBE (BASE) PORT + STEPPER NEEDLE =====
// ESP32-S3-DevKitC-1 + ENS161 + ENS210 + 28BYJ-48/ULN2003 + onboard RGB LED
//
// Ported from StuckAtPrototype/AirCube firmware (Base model) source:
//   ens210.c, ens16x_driver.c, led.c, led_color_lib.c.
//
// Air quality: uses the ENS161's own onboard AQI-UBA classification (register 0x21,
// 1-5) instead of AirCube's software-derived 0-500 "VOC Level". AQI-UBA is computed
// inside the chip by ScioSense's own algorithm, so it isn't reachable from software
// anyway. eTVOC and eCO2 below are the sensor's raw, uncorrected values.
//
// Only hardware you actually have is used: the two I2C sensors, the ESP32-S3
// board's own RGB LED, the stepper and WiFi. AirCube's button, its 3 external
// LEDs, the Pro sensors, Zigbee and BLE are not part of this sketch.
//
// Your addition: a stepper needle that points at the AQI-UBA rating.
//
// The WiFi page is modeled on AirCube's dashboard features: live readings with a
// color-coded VOC Level, live charts with adjustable depth, 5-minute min/avg/max
// history (same 32-byte slot layout and capacity as AirCube) with CSV export, and
// LED brightness. Open the board's IP address in a browser.
//
//   AQI-UBA   Rating       Needle
//   1         Excellent    0 deg
//   2         Good         90 deg
//   3         Moderate     115 deg
//   4         Poor         140 deg
//   5         Unhealthy    180 deg
//
// Timing: the sensors run from power-up, but nothing is read for the first 3 minutes
// (warm-up). After that one reading is taken per minute. The LED pulses blue until the
// first reading, then follows VOC Level from green to red.
//
// Power-on needle position is assumed to be 0 (home). Positive degrees = counter-clockwise.

#include <Wire.h>
#include <WiFi.h>
#include <WebServer.h>
#include <Adafruit_NeoPixel.h>
#include <math.h>
#include <string.h>

// ===== WiFi =====
const char* ssid = "";
const char* password = "";

// ===== Pins =====
#define I2C_SDA_PIN 9
#define I2C_SCL_PIN 8
#define LED_PIN 48                  // ESP32-S3-DevKitC-1 onboard RGB LED (GPIO48 on v1.0; v1.1 boards use GPIO38)
#define IN1 6
#define IN2 7
#define IN3 5
#define IN4 4

Adafruit_NeoPixel strip(1, LED_PIN, NEO_GRB + NEO_KHZ800);

// ===== Settings =====
#define WARMUP_MS 180000UL          // no readings for the first 3 minutes while the sensors warm up
#define SENSOR_PERIOD_MS 60000UL    // then one reading per minute (AirCube itself reads every second)
#define LED_PERIOD_MS 20UL          // LED animation tick (this is not a sensor reading)

// AirCube corrects ENS210 by -2 C inside its enclosure. Your board runs warmer
// (WiFi, ESP32-S3), so this is the ~10 F you measured. Re-tune with a reference thermometer.
#define TEMP_OFFSET_C 5.56f

// AirCube feeds the RAW ENS210 reading to the ENS161 for compensation (false).
// Set true to compensate with the offset-corrected (closer to room) temperature instead.
const bool COMPENSATE_WITH_CORRECTED_TEMP = false;


// ===== Needle / stepper =====
#define MAX_DEGREES 180.0
#define DIRECTION_SIGN 1            // change to -1 if positive turns the needle clockwise
const float BAND_ANGLE[5] = {0, 90, 115, 140, 180};
const char* BAND_NAME[5] = {"Excellent", "Good", "Moderate", "Poor", "Unhealthy"};
#define STABLE_SAMPLES 2            // a new band must show in this many readings in a row (about 2 minutes) before the needle moves

#define STEPS_PER_ROTATION 2048.0
#define DEGREES_PER_STEP (360.0 / STEPS_PER_ROTATION)
#define MAX_STEPS ((long)(MAX_DEGREES / DEGREES_PER_STEP + 0.5))

int stepSequence[4][4] = {
  {1, 0, 0, 0},
  {0, 1, 0, 0},
  {0, 0, 1, 0},
  {0, 0, 0, 1}
};
long currentSteps = 0;
int stepIndex = 0;
int motorSpeed = 3;                 // ms between steps (lower = faster)

// ===== AirCube VOC Level tables (main.c) =====
#define AQI_UBA_MIN 1
#define AQI_UBA_MAX 5
#define HUE_GREEN 21845

// ===== LED (led.c / led_color_lib.c) =====
#define INTENSITY_RAMP_MS 500
#define TRANSITION_SPEED 0.02f

float currentHue = HUE_GREEN;
uint16_t targetHue = HUE_GREEN;
float ledIntensity = 0.0f;
float ledIntensityTarget = 0.0f;
int ledBrightnessPct = 60;          // AirCube default; changed from the web page, not saved
int lastR = -1, lastG = -1, lastB = -1;

// ===== ENS210 =====
#define ENS210_ADDR 0x43
#define ENS210_REG_PART_ID 0x00
#define ENS210_REG_SYS_CTRL 0x10
#define ENS210_REG_SYS_STAT 0x11
#define ENS210_REG_SENS_RUN 0x21
#define ENS210_REG_SENS_START 0x22
#define ENS210_REG_T_VAL 0x30
#define ENS210_REG_H_VAL 0x33

uint8_t ens210T[2] = {0, 0};
uint8_t ens210H[2] = {0, 0};
float temperatureC = 0;             // raw ENS210 reading
float humidityPct = 0;
bool ens210Present = false;
bool ens210TempValid = false;
bool ens210HumValid = false;

// ===== ENS16X =====
#define ENS16X_ADDR 0x52
#define ENS16X_DEVICE_STATUS 0x20
#define ENS16X_OPMODE 0x10
#define ENS16X_REG_DATA_ETVOC 0x22
#define ENS16X_REG_DATA_ECO2 0x24
#define ENS16X_REG_DATA_AQI_UBA 0x21
#define ENS16X_REG_TH_IN 0x13       // TEMP_IN (2) then RH_IN (2)

#define ENS_OP_OK 0
#define ENS_WARM_UP 1
#define ENS_RESERVED 2
#define ENS_NO_VALID_OUTPUT 3
#define ENS_IDLE 1
#define ENS_STANDARD 2

bool ens16xPresent = false;
int ens16xStatus = ENS_NO_VALID_OUTPUT;
int ens16xTvoc = -1;
int ens16xEco2 = -1;
int ens16xAqiUba = -1;

// ===== Live values =====
int currentAqiUba = 0;              // 1-5, held at last known value if a read fails; 0 = no data yet
float tempCOut = 0;                 // offset-corrected temperature
bool autoMode = true;
int appliedBand = -1;
int candidateBand = -1;
int candidateCount = 0;

unsigned long lastSensorMs = 0;
unsigned long lastLedMs = 0;
unsigned long lastWarmMsgMs = 0;
unsigned long sensorsStartMs = 0;   // when the sensors were switched on
unsigned long lastReadingMs = 0;
unsigned long readingSeq = 0;       // counts valid readings so the page only charts new ones
bool firstStepDone = false;
bool haveReading = false;           // true after the first valid VOC reading

// ===== History (history.c): 5-minute min/avg/max windows, kept in RAM =====
#define HISTORY_CAPACITY 2016            // 7 days of 5-minute windows, same as AirCube
#define HISTORY_WINDOW_MS 300000UL       // 5 minutes
#define HISTORY_NO_DATA_S16 (-32768)     // channel had no valid samples in the window
#define HISTORY_NO_DATA_U16 65535

// Same 32-byte slot as AirCube. Temperature/humidity are x100; VOC Level, eCO2, eTVOC are raw.
struct __attribute__((packed)) HistorySlot {
  uint16_t sequence;
  int16_t t_a, t_n, t_x;                 // temperature avg/min/max (x100 C)
  int16_t h_a, h_n, h_x;                 // humidity avg/min/max (x100 %)
  uint16_t q_a, q_n, q_x;                // VOC Level
  uint16_t c_a, c_n, c_x;                // eCO2 (ppm)
  uint16_t v_a, v_n, v_x;                // eTVOC (ppb)
};
static_assert(sizeof(HistorySlot) == 32, "HistorySlot must be 32 bytes like AirCube");

HistorySlot histSlots[HISTORY_CAPACITY];
uint16_t histWrite = 0;                  // next slot to write
uint16_t histCount = 0;                  // valid entries, up to HISTORY_CAPACITY
uint16_t histNextSeq = 0;
unsigned long histLastFlushMs = 0;       // when the newest slot was saved (boot time until the first one)

struct HistAccum {
  float sumT, sumH;
  uint32_t sumQ, sumC, sumV;
  int16_t minT, maxT, minH, maxH;
  uint16_t minQ, maxQ, minC, maxC, minV, maxV;
  uint32_t samples, tCount, hCount, qCount, cCount, vCount;
  unsigned long windowStartMs;
};
HistAccum accum;

WebServer server(80);

const char INDEX_HTML[] PROGMEM = R"rawliteral(
<!DOCTYPE html>
<html lang="en">
<head>
<meta charset="utf-8">
<meta name="viewport" content="width=device-width, initial-scale=1">
<title>Air Quality Monitor</title>
<style>
:root { --bg:#0b1020; --card:#131a2e; --card2:#1a2340; --line:#25304d; --text:#e6ebf5; --muted:#8b97b3; --accent:#7c9cff; --good:#34d399; --warn:#fbbf24; --bad:#f87171; }
* { box-sizing: border-box; margin: 0; padding: 0; }
body { font-family: -apple-system, BlinkMacSystemFont, "Segoe UI", Roboto, Arial, sans-serif; background: var(--bg); color: var(--text); padding: 16px; }
.wrap { max-width: 980px; margin: 0 auto; }
header { display: flex; align-items: center; justify-content: space-between; gap: 12px; margin-bottom: 14px; flex-wrap: wrap; }
h1 { font-size: 20px; font-weight: 700; }
h1 small { font-size: 12px; color: var(--muted); font-weight: 500; margin-left: 8px; }
h2 { font-size: 14px; font-weight: 700; }
.chip { font-size: 12px; padding: 6px 10px; border-radius: 999px; background: var(--card2); color: var(--muted); border: 1px solid var(--line); }
.chip.ok { color: var(--good); border-color: #1f6f55; }
.chip.warn { color: var(--warn); border-color: #7a5c12; }
.chip.bad { color: var(--bad); border-color: #7a2a2a; }
nav { display: flex; gap: 6px; margin-bottom: 14px; }
nav button { flex: 1; padding: 10px; border: 1px solid var(--line); background: var(--card); color: var(--muted); border-radius: 10px; font-size: 14px; font-weight: 600; cursor: pointer; }
nav button.on { color: var(--text); background: var(--card2); border-color: var(--accent); }
.panel { background: var(--card); border: 1px solid var(--line); border-radius: 14px; padding: 16px; margin-bottom: 14px; }
.muted { color: var(--muted); }
.small { font-size: 12px; }
.row { display: flex; align-items: center; gap: 10px; flex-wrap: wrap; margin-bottom: 10px; }
.spacer { flex: 1; }
.hero { display: flex; align-items: center; gap: 22px; flex-wrap: wrap; }
.ring { width: 150px; height: 150px; border-radius: 50%; border: 10px solid var(--line); display: flex; flex-direction: column; align-items: center; justify-content: center; flex: none; transition: border-color .6s; }
.ring-num { font-size: 46px; font-weight: 800; line-height: 1; transition: color .6s; }
.ring-cap { font-size: 12px; color: var(--muted); margin-top: 6px; }
.hero-side { flex: 1; min-width: 220px; }
.rating { font-size: 30px; font-weight: 800; }
.scale { position: relative; display: flex; height: 12px; border-radius: 6px; overflow: visible; margin: 14px 0 6px; }
.scale .seg { flex: 1; }
.scale .seg:first-child { border-radius: 6px 0 0 6px; }
.scale .seg:nth-child(5) { border-radius: 0 6px 6px 0; }
.marker { position: absolute; top: -5px; width: 4px; height: 22px; background: #fff; border-radius: 2px; box-shadow: 0 0 0 2px var(--bg); left: 0; transition: left .6s; }
.scale-labels { display: flex; font-size: 11px; color: var(--muted); }
.scale-labels span { flex: 1; text-align: center; }
.warm { background: #0f2a4a; color: #bcd9ff; border: 1px solid #1d4a80; padding: 10px; border-radius: 10px; font-size: 13px; text-align: center; margin-bottom: 14px; display: none; }
.cards { display: grid; grid-template-columns: repeat(auto-fit, minmax(150px, 1fr)); gap: 10px; margin-bottom: 14px; }
.card { background: var(--card); border: 1px solid var(--line); border-radius: 14px; padding: 14px; }
.card .k { font-size: 11px; text-transform: uppercase; letter-spacing: .05em; color: var(--muted); font-weight: 700; }
.card .v { font-size: 26px; font-weight: 800; margin-top: 4px; }
.chart-title { font-size: 12px; font-weight: 700; color: var(--muted); text-transform: uppercase; letter-spacing: .05em; margin: 14px 0 6px; }
canvas { width: 100%; height: 170px; display: block; background: #0e1527; border-radius: 10px; border: 1px solid var(--line); }
button.btn, select { padding: 8px 12px; border: 1px solid var(--line); background: var(--card2); color: var(--text); border-radius: 8px; font-size: 13px; font-weight: 600; cursor: pointer; }
button.btn.primary { background: var(--accent); color: #0b1020; border-color: var(--accent); }
button.btn.on { background: var(--good); color: #062; border-color: var(--good); }
button.btn.danger { border-color: #7a2a2a; color: var(--bad); }
.btns { display: flex; gap: 6px; flex-wrap: wrap; }
.btns .btn { flex: 1; min-width: 60px; }
input[type=number] { flex: 1; min-width: 100px; padding: 9px; border-radius: 8px; border: 1px solid var(--line); background: #0e1527; color: var(--text); font-size: 14px; }
.bar { height: 10px; background: #0e1527; border-radius: 5px; overflow: hidden; border: 1px solid var(--line); }
.bar > div { height: 100%; width: 0; background: var(--accent); transition: width .3s; }
.bar-scale { display: flex; justify-content: space-between; font-size: 11px; color: var(--muted); margin-top: 3px; }
table { width: 100%; border-collapse: collapse; font-size: 13px; }
td, th { padding: 7px 6px; text-align: left; border-bottom: 1px solid var(--line); }
th { color: var(--muted); font-size: 11px; text-transform: uppercase; letter-spacing: .05em; }
.toast { min-height: 36px; text-align: center; font-size: 13px; padding: 9px; border-radius: 8px; margin-top: 12px; color: var(--muted); }
.toast.ok { background: #0f2f26; color: var(--good); }
.toast.err { background: #331616; color: var(--bad); }
footer { text-align: center; color: var(--muted); font-size: 12px; padding: 6px 0 20px; }
</style>
</head>
<body>
<div class="wrap">
<header>
  <h1>Air Quality Monitor<small>ENS161 + ENS210</small></h1>
  <div class="chip" id="chip">Connecting...</div>
</header>

<nav>
  <button data-tab="live" class="on">Live</button>
  <button data-tab="history">History</button>
  <button data-tab="needle">Needle</button>
</nav>
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
void loop() {
  server.handleClient();

  unsigned long now = millis();

  if (now - lastLedMs >= LED_PERIOD_MS) {
    lastLedMs = now;
    ledTick();
  }

  // Warm-up: the sensors are running, but nothing is read for the first 3 minutes.
  if (!warmupDone()) {
    if (now - lastWarmMsgMs >= 30000UL) {
      lastWarmMsgMs = now;
      Serial.printf("[Warm-up] %lu s until the first reading\n", (WARMUP_MS - (now - sensorsStartMs)) / 1000UL);
    }
    return;
  }

  // First reading as soon as warm-up ends, then one per minute.
  if (!firstStepDone || (now - lastSensorMs) >= SENSOR_PERIOD_MS) {
    if (!firstStepDone) {
      firstStepDone = true;
      historyResetAccum();              // the first 5-minute history window starts with the first reading
    }
    lastSensorMs = now;
    sensorStep();
  }
}

// ===================== I2C HELPERS =====================

bool i2cProbe(uint8_t addr) {
  Wire.beginTransmission(addr);
  return Wire.endTransmission() == 0;
}

bool i2cWrite(uint8_t addr, const uint8_t* data, uint8_t len) {
  Wire.beginTransmission(addr);
  for (uint8_t i = 0; i < len; i++) {
    Wire.write(data[i]);
  }
  return Wire.endTransmission() == 0;
}

bool i2cRead(uint8_t addr, uint8_t reg, uint8_t* buf, uint8_t len) {
  Wire.beginTransmission(addr);
  Wire.write(reg);
  if (Wire.endTransmission() != 0) return false;
  if (Wire.requestFrom(addr, len) != len) return false;
  for (uint8_t i = 0; i < len; i++) {
    buf[i] = Wire.read();
  }
  return true;
}

// ===================== ENS210 (ens210.c) =====================

void ens210Init() {
  ens210Present = false;

  Serial.print("ENS210 at 0x43... ");
  if (!i2cProbe(ENS210_ADDR)) {
    Serial.println("not present");
    return;
  }

  // Active mode, done before the PART_ID read so the device is awake.
  uint8_t sc[2] = {ENS210_REG_SYS_CTRL, 0x00};
  i2cWrite(ENS210_ADDR, sc, 2);
  delay(10);

  // PART_ID low 12 bits must be 0x210 (top nibble reads 0xA on real parts).
  uint8_t part[2] = {0, 0};
  if (i2cRead(ENS210_ADDR, ENS210_REG_PART_ID, part, 2)) {
    uint16_t partId = (uint16_t)part[0] | ((uint16_t)part[1] << 8);
    ens210Present = ((partId & 0x0FFF) == 0x0210);
    Serial.print("PART_ID 0x");
    Serial.print(partId, HEX);
    Serial.print(ens210Present ? " ok" : " UNEXPECTED");
  }
  if (!ens210Present) {
    Serial.println(" - not present");
    return;
  }

  // Continuous mode for temperature and humidity, then start.
  uint8_t run[2] = {ENS210_REG_SENS_RUN, 0x03};
  i2cWrite(ENS210_ADDR, run, 2);
  uint8_t start[2] = {ENS210_REG_SENS_START, 0x03};
  i2cWrite(ENS210_ADDR, start, 2);
  delay(250);

  uint8_t stat = 0;
  i2cRead(ENS210_ADDR, ENS210_REG_SYS_STAT, &stat, 1);
  Serial.print(", continuous mode, SYS_STAT 0x");
  Serial.println(stat, HEX);
}

// T_VAL / H_VAL are 3 bytes: [DATA_LSB, DATA_MSB, VALID(bit0)+CRC].
void ens210ReadEnvir() {
  ens210TempValid = false;
  ens210HumValid = false;
  if (!ens210Present) return;

  uint8_t d[3];

  memset(d, 0, sizeof(d));
  if (!i2cRead(ENS210_ADDR, ENS210_REG_T_VAL, d, 3)) {
    Serial.println("[ens210] Temperature read failed");
    return;
  }
  uint32_t tVal = (uint32_t)d[0] | ((uint32_t)d[1] << 8) | ((uint32_t)d[2] << 16);
  uint32_t tData = tVal & 0xFFFF;
  uint32_t tValid = (tVal >> 16) & 0x1;
  if (tValid) {
    ens210T[0] = d[0];
    ens210T[1] = d[1];
    float tinK = (float)tData / 64.0f;
    temperatureC = tinK - 273.15f;
    ens210TempValid = true;
  }

  memset(d, 0, sizeof(d));
  if (!i2cRead(ENS210_ADDR, ENS210_REG_H_VAL, d, 3)) {
    Serial.println("[ens210] Humidity read failed");
    return;
  }
  uint32_t hVal = (uint32_t)d[0] | ((uint32_t)d[1] << 8) | ((uint32_t)d[2] << 16);
  uint32_t hData = hVal & 0xFFFF;
  uint32_t hValid = (hVal >> 16) & 0x1;
  if (hValid) {
    ens210H[0] = d[0];
    ens210H[1] = d[1];
    humidityPct = (float)hData / 512.0f;
    ens210HumValid = true;
  }
}

// ===================== ENS16X (ens16x_driver.c) =====================

int ens16xGetDeviceStatus() {
  uint8_t b = 0;
  if (!i2cRead(ENS16X_ADDR, ENS16X_DEVICE_STATUS, &b, 1)) {
    ens16xStatus = ENS_NO_VALID_OUTPUT;
    return -1;
  }
  // bit 1 NEWDAT, bits 2-3 VALIDITY (0 OK, 1 warm-up, 2 initial start-up, 3 no valid output)
  ens16xStatus = (b >> 2) & 0x03;
  return b;
}

int ens16xGetOpmode() {
  uint8_t b = 0xFF;
  i2cRead(ENS16X_ADDR, ENS16X_OPMODE, &b, 1);
  return b;
}

void ens16xSetOpmode(int mode) {
  // Go through IDLE first, then to the requested mode, then confirm.
  uint8_t idle[2] = {ENS16X_OPMODE, ENS_IDLE};
  i2cWrite(ENS16X_ADDR, idle, 2);
  delay(10);
  uint8_t want[2] = {ENS16X_OPMODE, (uint8_t)mode};
  i2cWrite(ENS16X_ADDR, want, 2);
  delay(10);

  if (ens16xGetOpmode() == mode) {
    Serial.println("[ens16x] Mode change success");
  } else {
    Serial.println("[ens16x] Error changing modes");
  }
}

int ens16xReadEtvoc() {
  uint8_t b[2] = {0, 0};
  if (!i2cRead(ENS16X_ADDR, ENS16X_REG_DATA_ETVOC, b, 2)) {
    ens16xTvoc = -1;
    return -1;
  }
  ens16xTvoc = (int)((uint16_t)b[0] | ((uint16_t)b[1] << 8));   // raw, no offset
  return ens16xTvoc;
}

int ens16xReadEco2() {
  uint8_t b[2] = {0, 0};
  if (!i2cRead(ENS16X_ADDR, ENS16X_REG_DATA_ECO2, b, 2)) {
    ens16xEco2 = -1;
    return -1;
  }
  ens16xEco2 = (int)((uint16_t)b[0] | ((uint16_t)b[1] << 8));   // raw, no offset (chip already floors at 400)
  return ens16xEco2;
}

// AQI-UBA is bits 0-2 of register 0x21: the chip's own 1-5 hygienic rating, computed
// onboard from its internal (uncorrected) eTVOC signal. Not affected by our offsets.
int ens16xReadAqiUba() {
  uint8_t b = 0;
  if (!i2cRead(ENS16X_ADDR, ENS16X_REG_DATA_AQI_UBA, &b, 1)) {
    ens16xAqiUba = -1;
    return -1;
  }
  ens16xAqiUba = b & 0x07;
  if (ens16xAqiUba < AQI_UBA_MIN || ens16xAqiUba > AQI_UBA_MAX) {
    ens16xAqiUba = -1;   // outside the defined 1-5 range (e.g. still warming up)
  }
  return ens16xAqiUba;
}

// Writes TEMP_IN (1/64 K) and RH_IN (1/512 %) in one transaction, like the firmware.
void ens16xWriteEns210Data(const uint8_t* t, const uint8_t* h) {
  uint8_t d[5] = {ENS16X_REG_TH_IN, t[0], t[1], h[0], h[1]};
  if (!i2cWrite(ENS16X_ADDR, d, 5)) {
    Serial.println("[ens16x] Compensation write failed; VOC output uses stale temp/RH");
  }
}

const char* ens16xStatusStr(int s) {
  switch (s) {
    case ENS_OP_OK: return "OK";
    case ENS_WARM_UP: return "Warming Up";
    case ENS_NO_VALID_OUTPUT: return "No Valid Output";
    case ENS_RESERVED: return "Reserved";
    default: return "Unknown";
  }
}

void ens16xInit() {
  Serial.print("ENS16X at 0x52... ");
  if (!i2cProbe(ENS16X_ADDR)) {
    Serial.println("NOT FOUND");
    ens16xPresent = false;
    return;
  }
  ens16xPresent = true;

  uint8_t id[2] = {0, 0};
  i2cRead(ENS16X_ADDR, 0x00, id, 2);
  uint16_t partId = (uint16_t)id[0] | ((uint16_t)id[1] << 8);
  Serial.print("part ID 0x");
  Serial.print(partId, HEX);

  ens16xGetDeviceStatus();
  Serial.print(", status: ");
  Serial.println(ens16xStatusStr(ens16xStatus));

  if (ens16xGetOpmode() != ENS_STANDARD) {
    Serial.println("[ens16x] setting mode to STANDARD");
    ens16xSetOpmode(ENS_STANDARD);
  } else {
    Serial.println("[ens16x] operating mode already STANDARD");
  }
  // AirCube reads eTVOC once here; we skip it so nothing is read during warm-up.
}

// ===================== AQI-UBA =====================

// AQI-UBA (1-5) -> band index 0..4 (Excellent .. Unhealthy).
int aqiUbaToBand(int aqiUba) {
  if (aqiUba < AQI_UBA_MIN) aqiUba = AQI_UBA_MIN;
  if (aqiUba > AQI_UBA_MAX) aqiUba = AQI_UBA_MAX;
  return aqiUba - 1;
}

// ===================== SENSOR STEP (sensor_task, Base branch) =====================
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
